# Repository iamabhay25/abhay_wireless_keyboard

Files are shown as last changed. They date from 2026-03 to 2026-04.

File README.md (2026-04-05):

# Abhay's Wireless Keyboard
# VELUNE
This is my wireless keyboard for everyday personal use.<br><br>
I made this because I didn't have a keyboard and instead of going to the store and buying one, I thought, "why not build one myself?".<br><br>
So I set out on my pursuit to build a custom keyboard which, as I learned, has a lot of things to learn to get it right.<br><br>
However, in the end, I gained a lot of knowledge on the seemingly simple art of designing a keyboard and got a chance to design something that I was proud of.<br><br>
Using my keyboard is like any other keyboard, so you can just start by typing!<br><br>
Overall, I really enjoyed doing this.<br><br>
Credits for Hackclub / Blueprint for sponsoring this.
<br>
______________________________________________________
Bill of Materials:<br>
<br>
Switches:<br>
78 × GATERON Milky Yellow Cherry MX-style switches: $27.74<br>   

<br>
<br>
Electronics:<br>
1 × Custom PCB (78-key): $43.98<br>

_____________________________________

1 × Raspberry Pi Pico<br>
+<br>
78 × Diodes (1N4148)<br>
+<br>
Raspberry Pi Pico Header Pins<br>
+<br>
PCB Mount Stabilizers<br>
+<br>
Keycap Set<br><br>

= $25.78 / with free shipping

<br>
Case Assembly:<br>
8 × M3 screws (8mm length): $4.66<br>
<br>
Case Parts<br>
Top case, bottom case: (PRINTING LEGION) (SHIPPING: $5)<br>
<br>
Final Count Summary<br>
Switches: 78<br>
Diodes: 78<br>
Screws: 8 total (M3)<br>
Microcontroller: 1 Pico<br>
FINAL COST: $107.16$<br>
<br>

____________________________________

Schematic:
Screenshot 2026-03-23 at 11 47 16 AM<br>
<br><br>
PCB:<br>
Screenshot 2026-04-05 at 1 36 23 PM<br>
Screenshot 2026-04-05 at 1 36 52 PM<br>
<br><br>
Wireless Keyboard Top Case CAD:<br>
Screenshot 2026-03-31 at 7 14 04 PM<br>
<br><br>
Wireless Keyboard Bottom Case CAD:<br>
Screenshot 2026-03-31 at 7 14 00 PM<br>
<br><br>
Final Wireless Keyboard Assembly:<br>
Screenshot 2026-04-05 at 3 41 43 PM<br>
Screenshot 2026-04-05 at 3 47 14 PM<br>
<br><br>

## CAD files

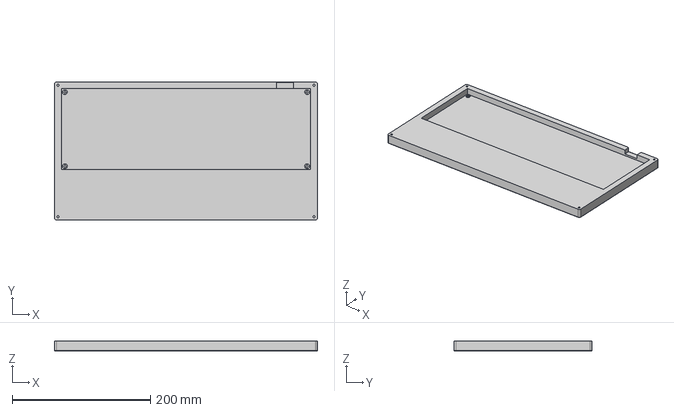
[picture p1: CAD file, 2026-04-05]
CAD/wireless keyboard bottom.step
380.0 x 200.0 x 15.0 mm

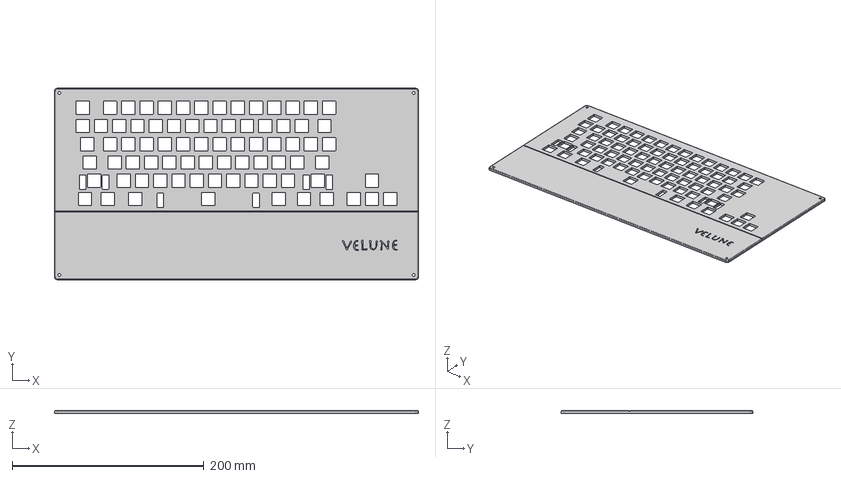
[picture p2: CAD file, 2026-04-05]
CAD/wireless keyboard top.step
380.0 x 200.0 x 3.00 mm

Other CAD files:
ASSEMBLY/wireless keyboard assembly.f3z
wireless+keyboard+bottom.stp
wireless+keyboard+top.stp

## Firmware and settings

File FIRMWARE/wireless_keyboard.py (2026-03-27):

import board
from kmk.kmk_keyboard import KMKKeyboard
from kmk.keys import KC
from kmk.scanners import DiodeOrientation

keyboard = KMKKeyboard()

# =========================
# MATRIX CONFIGURATION
# =========================

keyboard.col_pins = (
    board.GP0, board.GP1, board.GP2, board.GP3,
    board.GP4, board.GP5, board.GP6, board.GP7,
    board.GP8, board.GP9, board.GP10, board.GP11,
    board.GP12, board.GP13
)

keyboard.row_pins = (
    board.GP14, board.GP15, board.GP16,
    board.GP17, board.GP18, board.GP19
)

keyboard.diode_orientation = DiodeOrientation.COL2ROW

# =========================
# KEYMAP (78-KEY WORKING LAYOUT)
# =========================

keyboard.keymap = [
    [
        # Row 0
        KC.ESC, KC.N1, KC.N2, KC.N3, KC.N4, KC.N5, KC.N6, KC.N7, KC.N8, KC.N9, KC.N0, KC.MINS, KC.EQL, KC.NO,

        # Row 1
        KC.TAB, KC.Q, KC.W, KC.E, KC.R, KC.T, KC.Y, KC.U, KC.I, KC.O, KC.P, KC.LBRC, KC.RBRC, KC.NO,

        # Row 2
        KC.CAPS, KC.A, KC.S, KC.D, KC.F, KC.G, KC.H, KC.J, KC.K, KC.L, KC.SCLN, KC.QUOT, KC.ENT, KC.NO,

        # Row 3
        KC.LSFT, KC.Z, KC.X, KC.C, KC.V, KC.B, KC.N, KC.M, KC.COMM, KC.DOT, KC.SLSH, KC.RSFT, KC.UP, KC.NO,

        # Row 4
        KC.LCTL, KC.LGUI, KC.LALT, KC.SPC, KC.SPC, KC.SPC, KC.RALT, KC.RGUI, KC.LEFT, KC.DOWN, KC.RIGHT, KC.NO, KC.NO, KC.NO,

        # Row 5 (unused row)
        KC.NO, KC.NO, KC.NO, KC.NO, KC.NO, KC.NO, KC.NO, KC.NO, KC.NO, KC.NO, KC.NO, KC.NO, KC.NO, KC.NO
    ]
]

# =========================
# START KEYBOARD
# =========================

if __name__ == '__main__':
    keyboard.go()

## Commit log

2026-03-23 Expand README with Bill of Materials for keyboard
    Added a detailed Bill of Materials for the wireless keyboard project, including components and quantities.
2026-03-23 Update README with schematic and CAD images
    Added images for schematic, PCB, and CAD designs.
2026-03-23 Replace PCB image in README
    Updated PCB image in README with a new screenshot.
2026-03-23 Rename Wireless Keyboard.kicad_pcb to asdwasds
2026-03-23 Rename asdwasds to wireless keyboard.kicad/pcb
2026-03-23 Rename Wireless Keyboard.kicad_pcb to PCB/Wireless Keyboard.kicad_pcb
    [Wireless Keyboard.kicad_pcb]
2026-03-23 Rename Wireless Keyboard.kicad_pro to PCB/Wireless Keyboard.kicad_pro
2026-03-23 Rename Wireless Keyboard.kicad_sch to PCB/Wireless Keyboard.kicad_sch
    [Wireless Keyboard.kicad_sch]
2026-03-23 Add wireless keyboard bottom CAD file
    [wireless+keyboard+bottom.stp]
2026-03-23 Add wireless keyboard top CAD file
    [wireless+keyboard+top.stp]
2026-03-23 Update images in README for keyboard CAD
2026-03-27 Update README with new CAD images and final build
    Added new images and updated existing ones for the wireless keyboard CAD and final build.
2026-03-27 Fix formatting for switches and keycaps section
2026-03-27 Update switch description in README
2026-03-27 Update final wireless keyboard build image
2026-03-31 Update switch details in README
2026-04-01 Update screenshots for wireless keyboard CAD and build
2026-04-03 Revise bill of materials and update final cost
    Updated bill of materials and final cost.
2026-04-03 Fix typo in case parts description
2026-04-05 Rename wireless keyboard bottom.step to CAD/wireless keyboard bottom.step
    [wireless keyboard bottom.step]
2026-04-05 Rename wireless keyboard top.step to CAD/wireless keyboard top.step
    [wireless keyboard top.step]
2026-04-05 Rename wireless keyboard assembly.f3z to ASSEMBLY/wireless keyboard assembly.f3z
    [wireless keyboard assembly.f3z]
